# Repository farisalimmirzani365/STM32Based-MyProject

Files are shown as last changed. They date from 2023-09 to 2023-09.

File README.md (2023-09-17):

# STM32Based-MyProject
The Board is based on the STM32 microcontroller, with the Blue Pill STM32F103 serving as the reference material for schematic design. This board is equipped with communication options, either the nRF24L01 or LoRa-02, which can be externally selected according to the user's preference. Additionally, the board features an integrated ADXL345 sensor. It includes a TF-Card for additional data storage. Furthermore, the board can be augmented with an external TFT LCD, which users can purchase separately.

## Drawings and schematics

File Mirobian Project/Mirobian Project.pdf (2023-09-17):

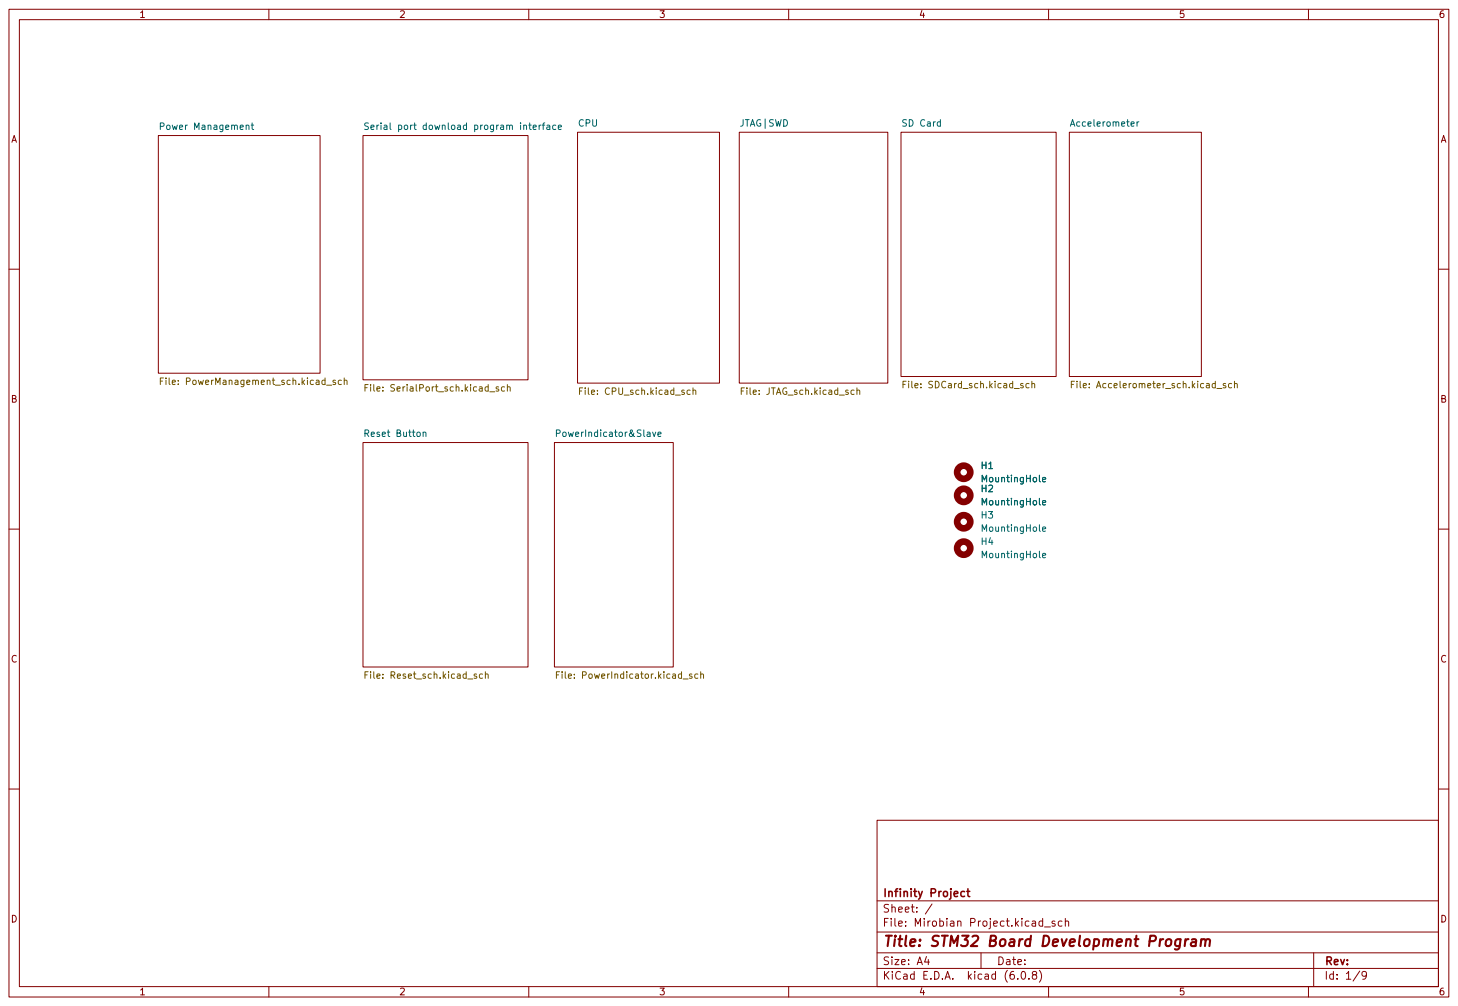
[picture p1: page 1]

Serial port download program interface File: SerialPort_sch.kicad_sch Reset Button File: Reset_sch.kicad_sch

PowerIndicator&Slave File: PowerIndicator.kicad_sch

Infinity Project
File: Mirobian Project.kicad_sch Sheet: /
Id: 1/9 Title: STM32 Board Development Program

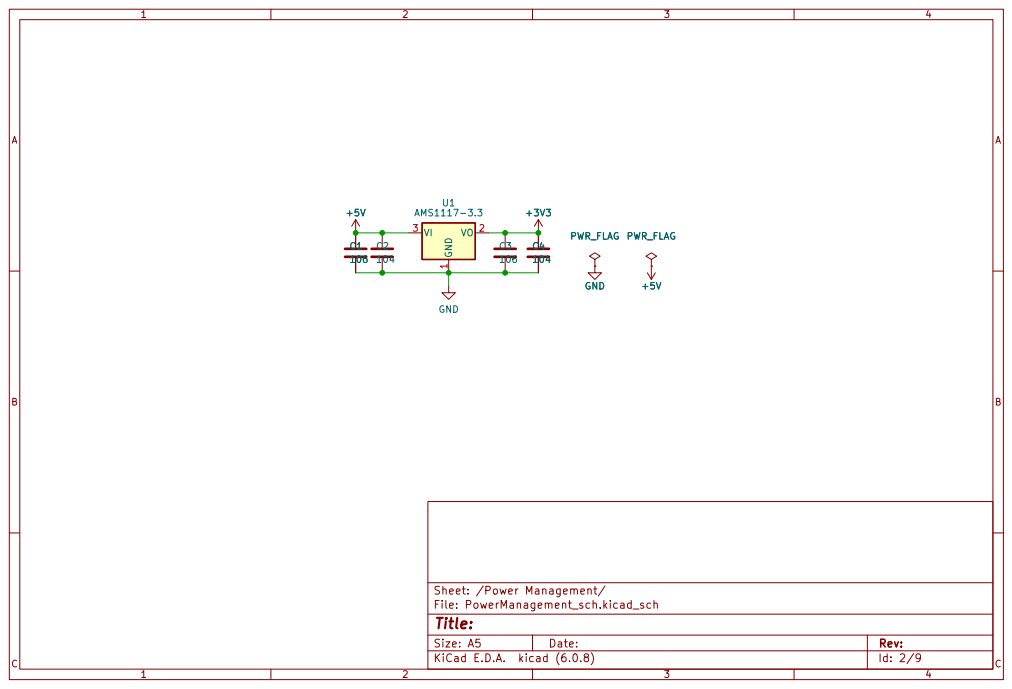
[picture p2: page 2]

Sheet: /Power Management/ GND

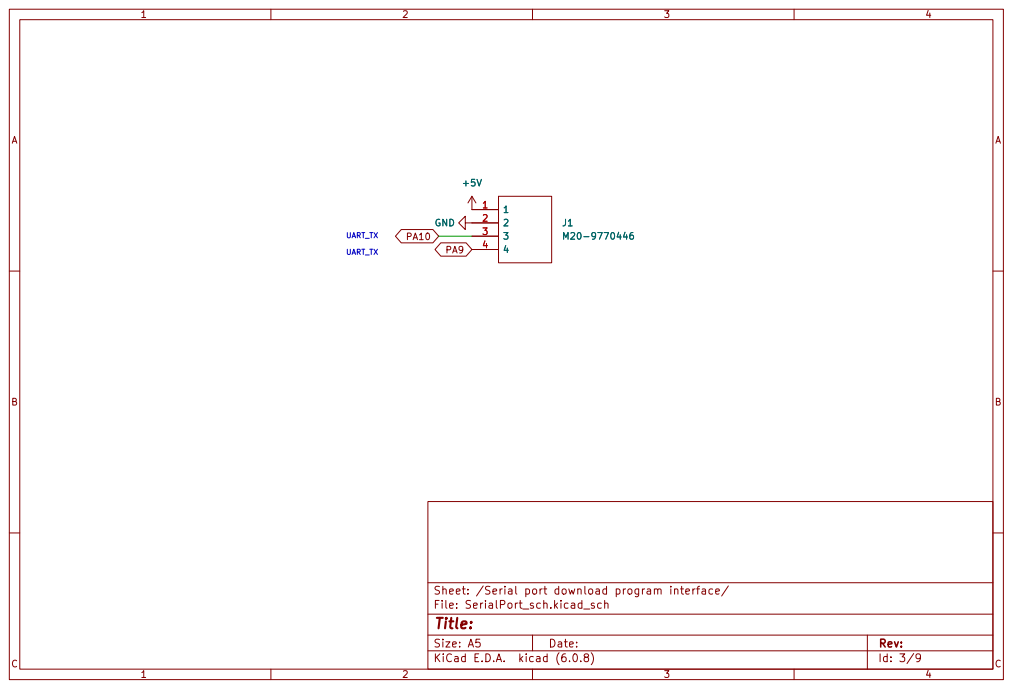
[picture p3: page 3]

Sheet: /Serial port download program interface/ GND

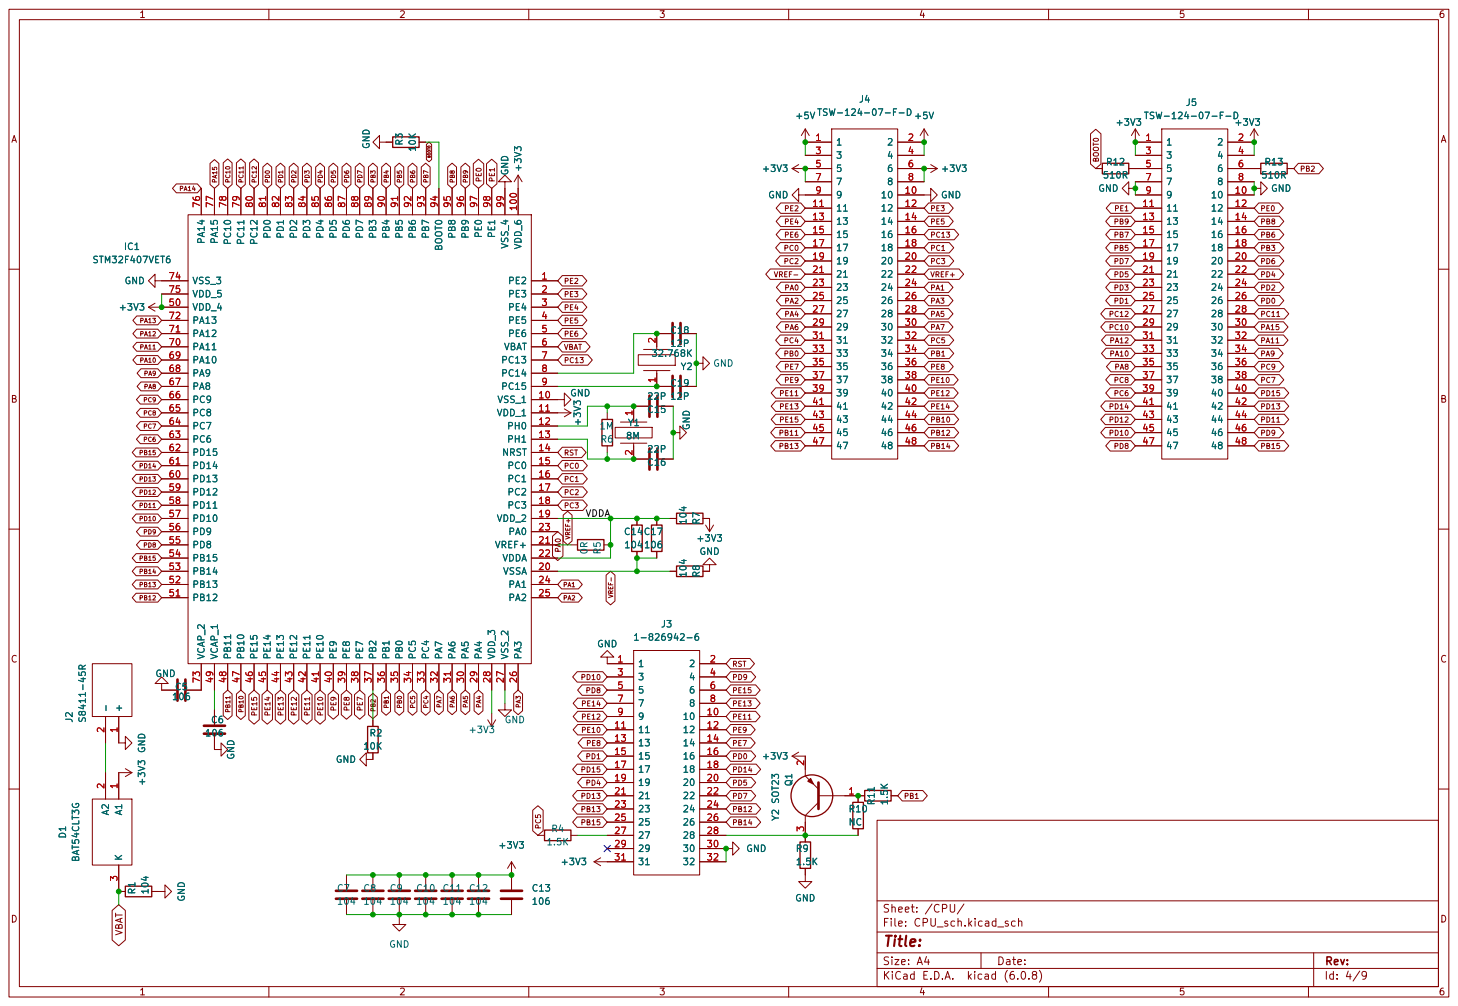
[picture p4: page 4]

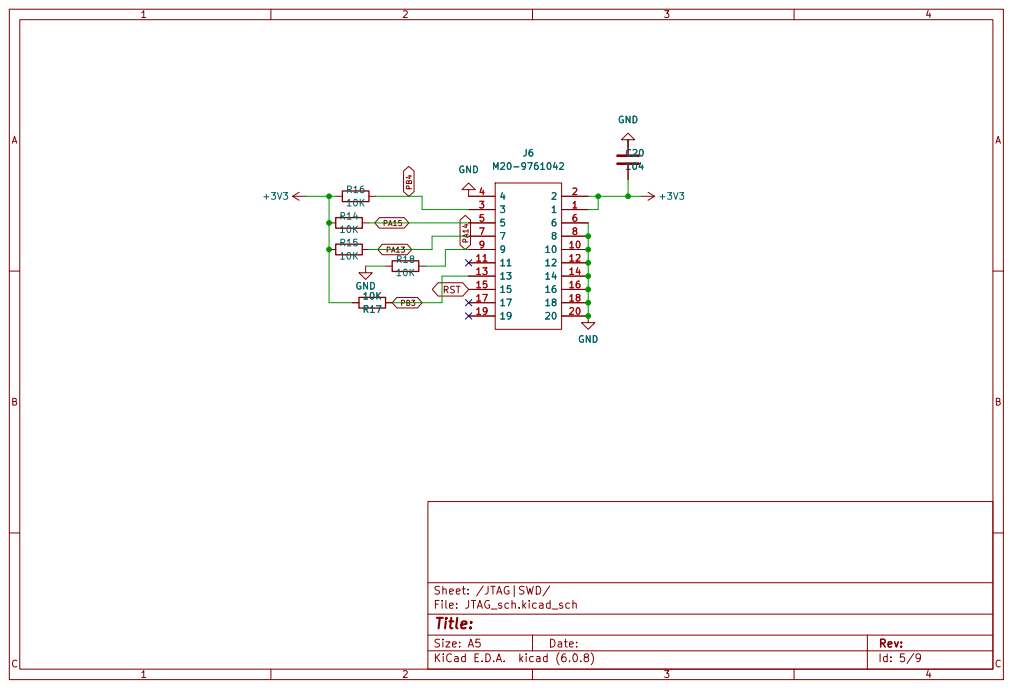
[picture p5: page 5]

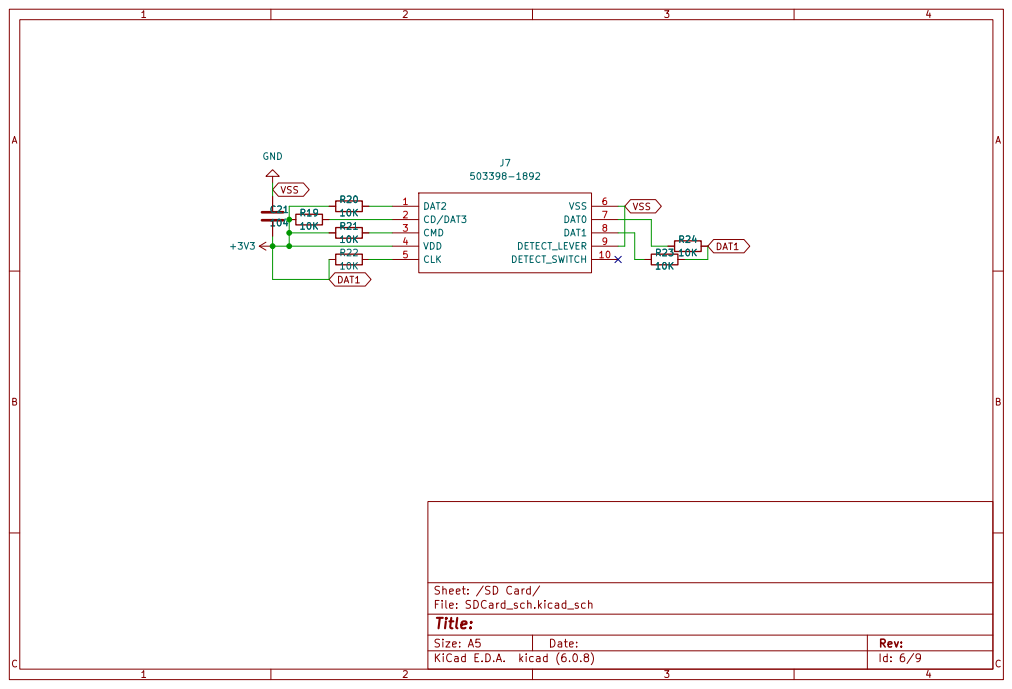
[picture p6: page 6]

File: SDCard_sch.kicad_sch Sheet: /SD Card/ R19

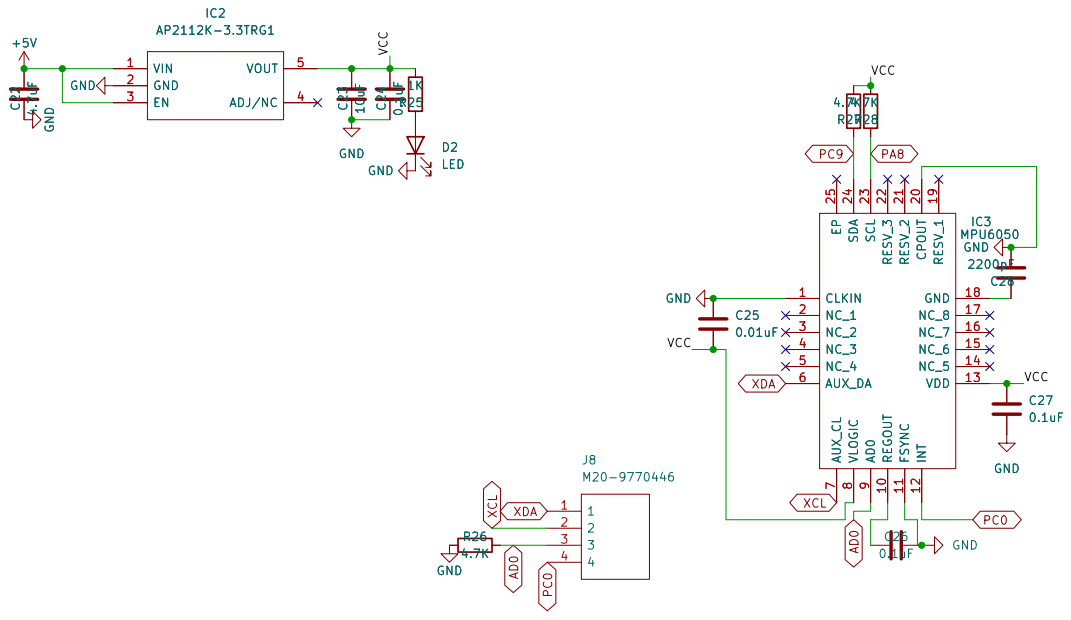
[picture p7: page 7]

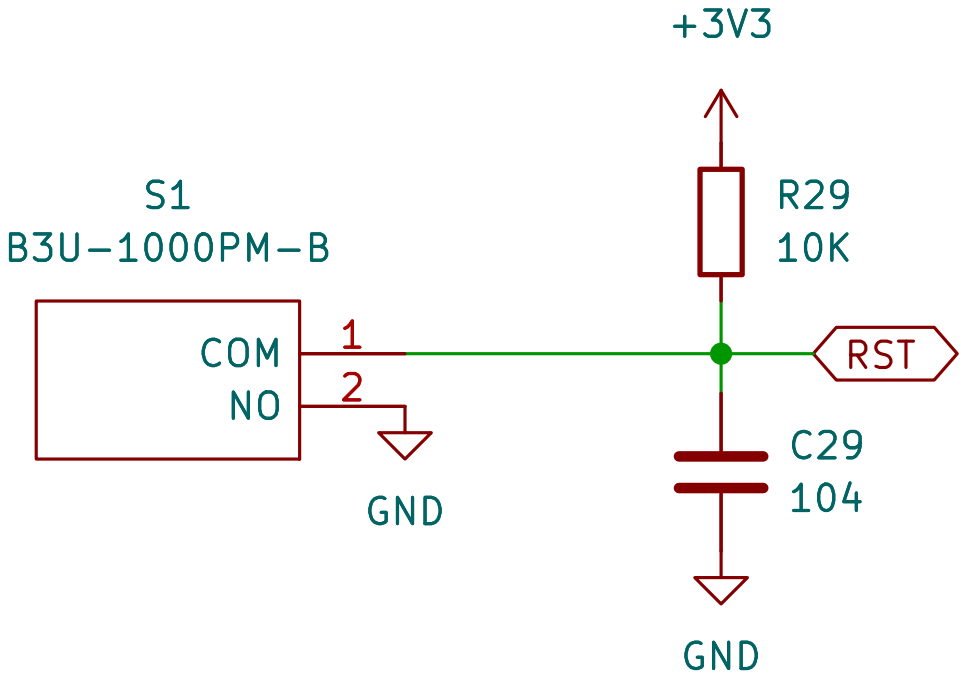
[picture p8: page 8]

File: Reset_sch.kicad_sch Sheet: /Reset Button/
Id: 8/9 Title:

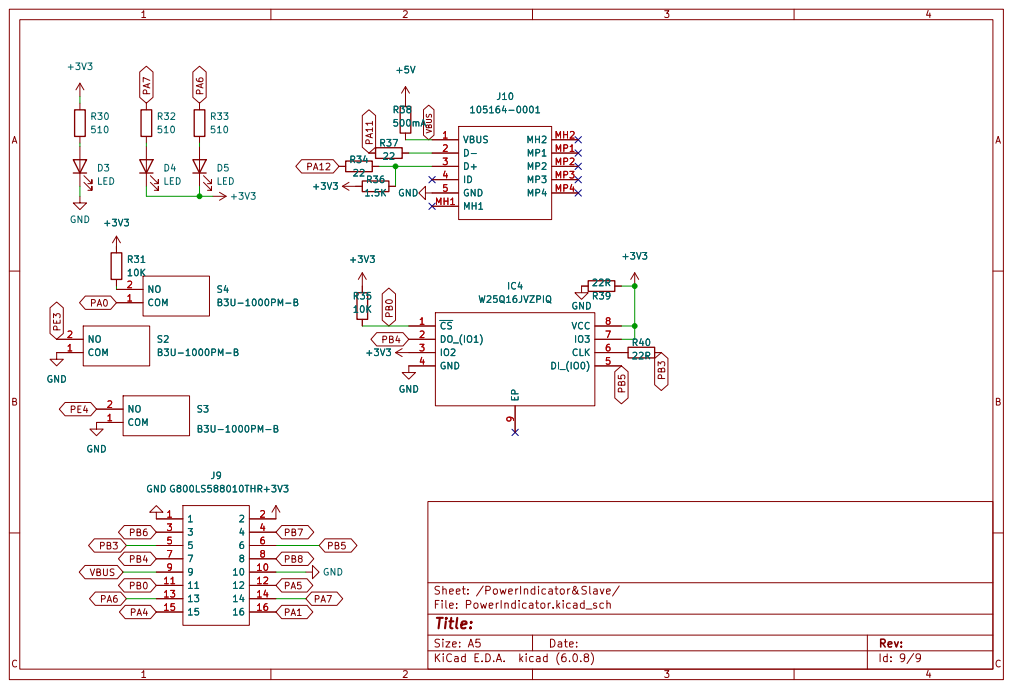
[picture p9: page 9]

File: PowerIndicator.kicad_sch Sheet: /PowerIndicator&Slave/

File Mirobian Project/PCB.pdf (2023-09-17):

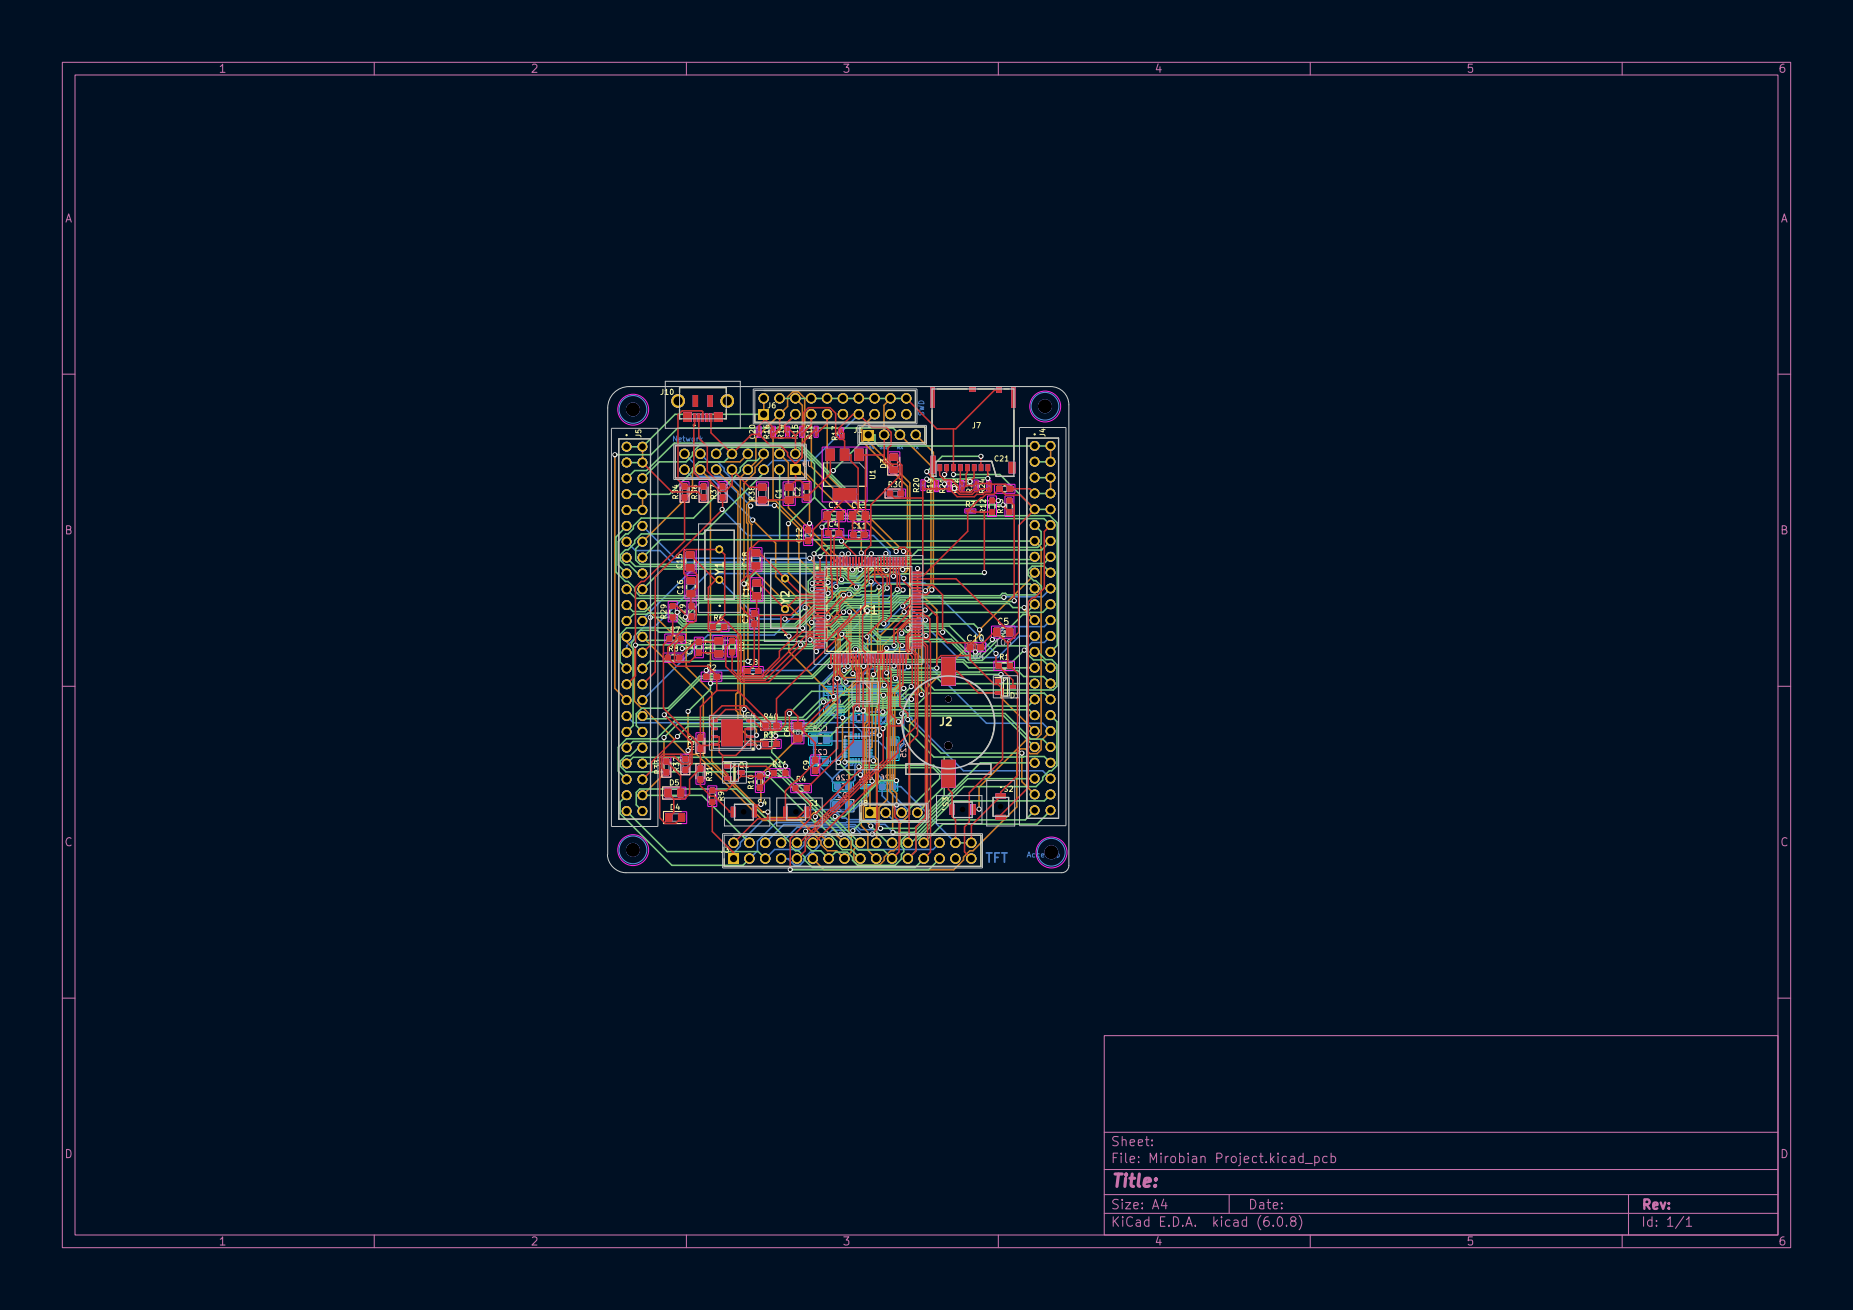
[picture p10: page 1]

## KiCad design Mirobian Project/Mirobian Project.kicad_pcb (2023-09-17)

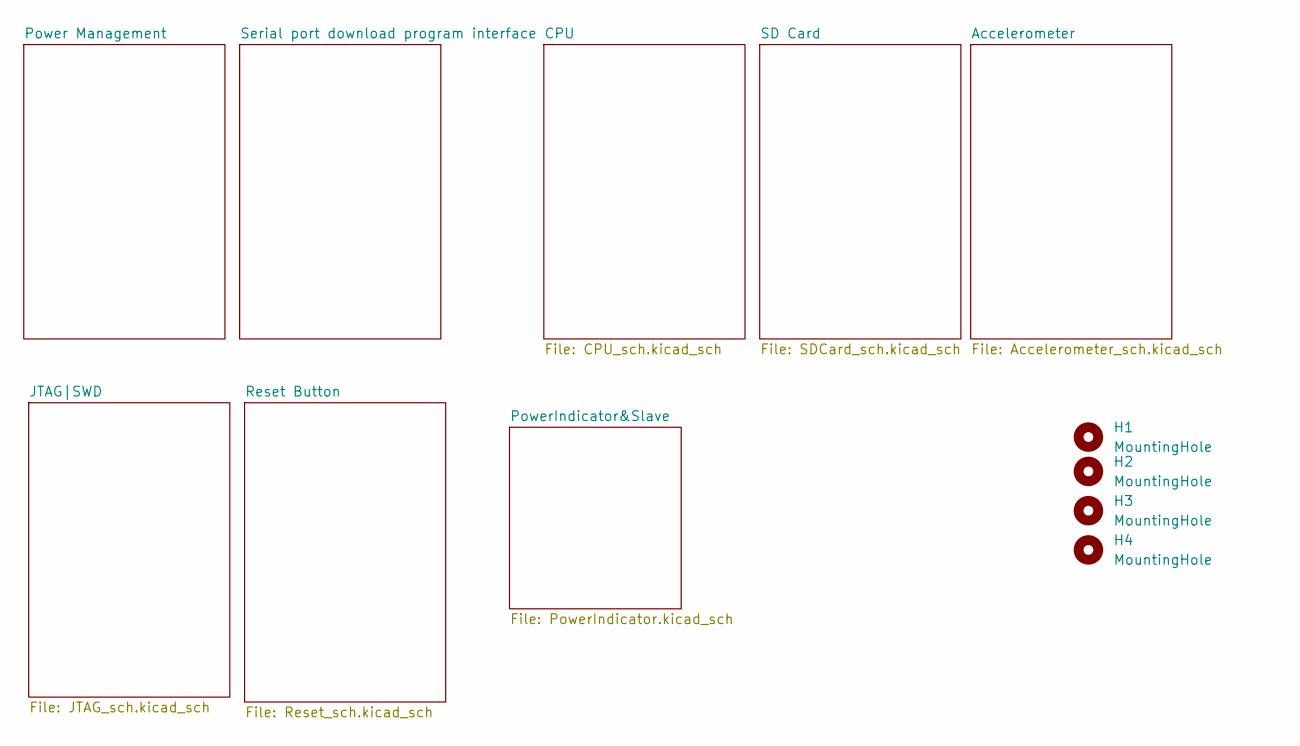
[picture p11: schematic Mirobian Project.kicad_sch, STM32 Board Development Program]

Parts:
H1, H2, H3, H4: MountingHole; MountingHole_2.2mm_M2

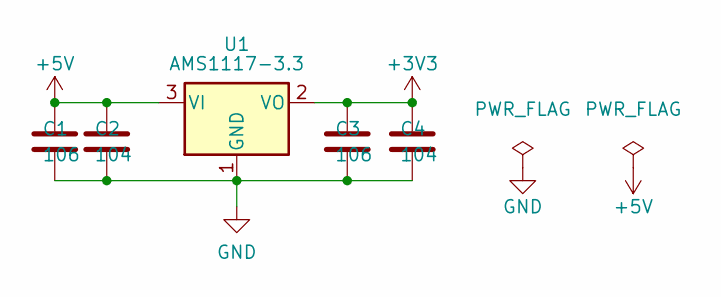
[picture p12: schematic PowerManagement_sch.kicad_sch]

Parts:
C1, C3: 106; C_0805_2012Metric_Pad1.18x1.45mm_HandSolder
C2, C4: 104; C_0603_1608Metric_Pad1.08x0.95mm_HandSolder
U1: AMS1117-3.3; SOT-223-3_TabPin2

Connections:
+5V: C1.1, C2.1, U1.3 (VI); also elsewhere on the board
DAT1: C3.1, C4.1, U1.2 (VO); also elsewhere on the board
VSS: C1.2, C2.2, C3.2, C4.2, U1.1 (GND); also elsewhere on the board

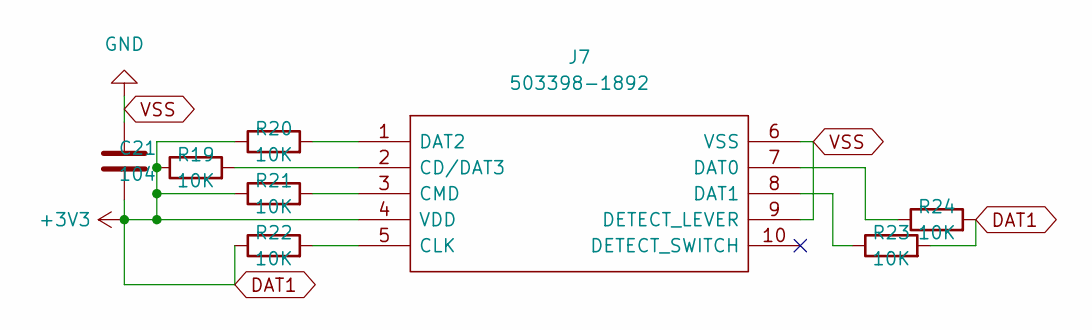
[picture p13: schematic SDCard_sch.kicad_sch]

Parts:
C21: 104; C_0603_1608Metric_Pad1.08x0.95mm_HandSolder
J7: 503398-1892; Manufacturer_Part_Number 503398-1892; Mouser Part Number 538-503398-1892
R19, R20, R21, R22, R23, R24: 10K; R_0201_0603Metric_Pad0.64x0.40mm_HandSolder

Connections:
DAT1: C21.2, J7.4 (VDD), R19.1, R20.1, R21.1, R22.1, R23.2, R24.2; also elsewhere on the board
unnamed: J7.1 (DAT2), R20.2
unnamed: J7.2 (CD/DAT3), R19.2
unnamed: J7.3 (CMD), R21.2
unnamed: J7.5 (CLK), R22.2
unnamed: J7.7 (DAT0), R24.1
unnamed: J7.8 (DAT1), R23.1
VSS: C21.1, J7.6 (VSS), J7.9 (DETECT_LEVER); also elsewhere on the board

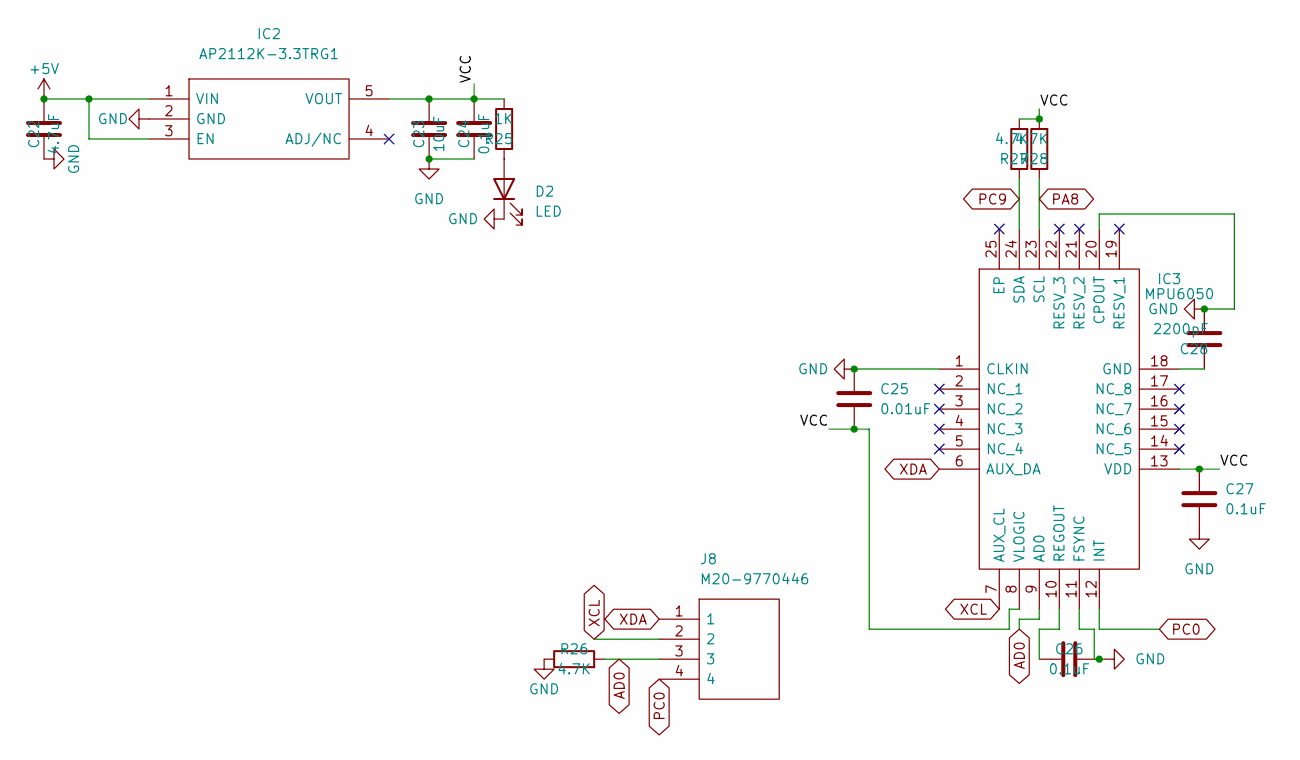
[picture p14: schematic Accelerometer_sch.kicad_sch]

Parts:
C22: 4.7uF; C_0603_1608Metric_Pad1.08x0.95mm_HandSolder
C23: 10uF; C_0603_1608Metric_Pad1.08x0.95mm_HandSolder
C24, C26, C27: 0.1uF; C_0603_1608Metric_Pad1.08x0.95mm_HandSolder
C25: 0.01uF; C_0805_2012Metric_Pad1.18x1.45mm_HandSolder
C28: 2200pF; C_0805_2012Metric_Pad1.18x1.45mm_HandSolder
D2: LED; LED_0805_2012Metric_Pad1.15x1.40mm_HandSolder
IC2: AP2112K-3.3TRG1; SOT95P282X130-5N; Manufacturer_Part_Number AP2112K-3.3TRG1; Mouser Part Number 621-AP2112K-3.3TRG1
IC3: MPU6050; Manufacturer_Part_Number MPU6050
J8: M20-9770446; HDRV4W64P0X254_1X4_1016X254X834P; Manufacturer_Part_Number M20-9770446; Mouser Part Number 855-M20-9770446
R25: 1K; R_0201_0603Metric_Pad0.64x0.40mm_HandSolder
R26, R27, R28: 4.7K; C_0603_1608Metric_Pad1.08x0.95mm_HandSolder

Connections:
+5V: C22.2, IC2.1 (VIN), IC2.3 (EN); also elsewhere on the board
/Accelerometer/VCC: C23.2, C24.2, C25.2, C27.1, IC2.5 (VOUT), IC3.8 (VLOGIC), IC3.13 (VDD), R25.2, R27.2, R28.2
AD0: IC3.9 (AD0), J8.3, R26.2
unnamed: C26.1, IC3.10 (REGOUT)
unnamed: C28.1, IC3.18 (GND)
unnamed: D2.2 (A), R25.1
PA8: IC3.23 (SCL), R28.1; also elsewhere on the board
PC0: IC3.12 (INT), J8.4; also elsewhere on the board
PC9: IC3.24 (SDA), R27.1; also elsewhere on the board
VSS: C22.1, C23.1, C24.1, C25.1, C26.2, C27.2, C28.2, D2.1 (K), IC2.2 (GND), IC3.1 (CLKIN), IC3.11 (FSYNC), IC3.20 (CPOUT), R26.1; also elsewhere on the board
XCL: IC3.7 (AUX_CL), J8.2
XDA: IC3.6 (AUX_DA), J8.1

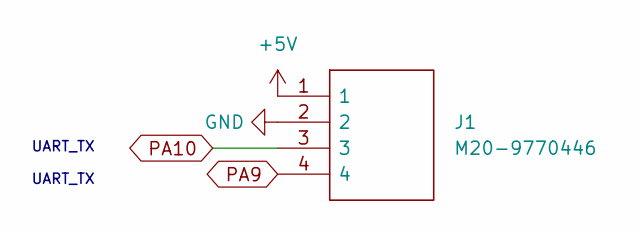
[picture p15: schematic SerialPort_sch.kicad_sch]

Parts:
J1: M20-9770446; HDRV4W64P0X254_1X4_1016X254X834P; Manufacturer_Part_Number M20-9770446; Mouser Part Number 855-M20-9770446

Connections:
+5V: J1.1; also elsewhere on the board
PA9: J1.4; also elsewhere on the board
PA10: J1.3; also elsewhere on the board
VSS: J1.2; also elsewhere on the board

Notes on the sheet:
UART_TX

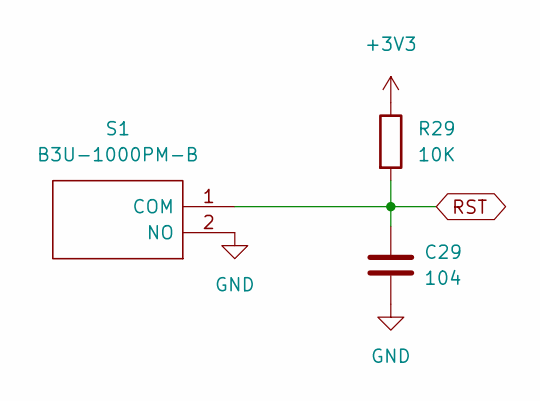
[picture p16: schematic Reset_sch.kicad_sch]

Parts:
C29: 104; C_0603_1608Metric_Pad1.08x0.95mm_HandSolder
R29: 10K; R_0603_1608Metric_Pad0.98x0.95mm_HandSolder
S1: B3U-1000PM-B; B3U1000PMB; Manufacturer_Part_Number B3U-1000PM-B; Mouser Part Number 653-B3U-1000PM-B

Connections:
DAT1: R29.1; also elsewhere on the board
RST: C29.1, R29.2, S1.1 (COM); also elsewhere on the board
VSS: C29.2, S1.2 (NO); also elsewhere on the board

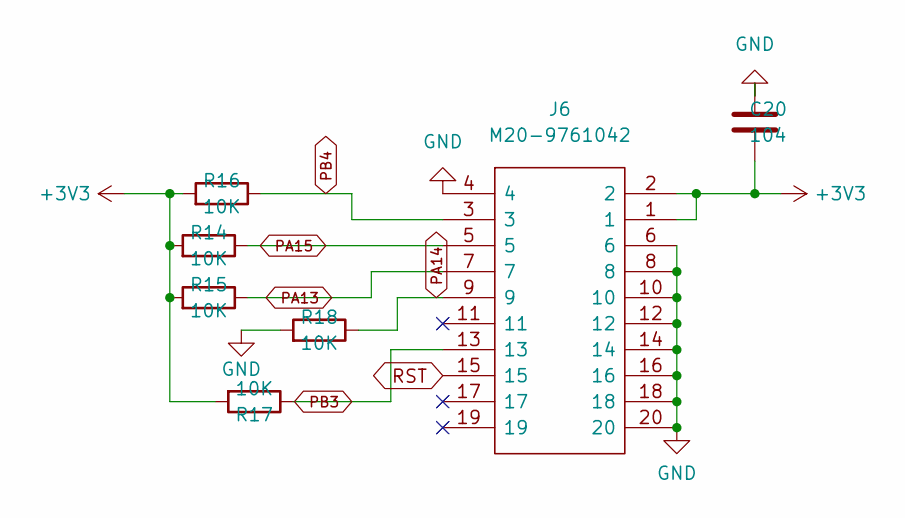
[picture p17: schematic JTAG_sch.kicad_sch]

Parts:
C20: 104; C_0201_0603Metric_Pad0.64x0.40mm_HandSolder
J6: M20-9761042; HDRV20W64P254_2X10_2540X508X838P; Manufacturer_Part_Number M20-9761042; Mouser Part Number 855-M20-9761042
R14, R15, R16, R17, R18: 10K; R_0201_0603Metric_Pad0.64x0.40mm_HandSolder

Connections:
DAT1: C20.2, J6.1, J6.2, R14.2, R15.2, R16.2, R17.2; also elsewhere on the board
PA13: J6.7, R15.1; also elsewhere on the board
PA14: J6.9, R18.1; also elsewhere on the board
PA15: J6.5, R14.1; also elsewhere on the board
PB3: J6.13, R17.1; also elsewhere on the board
PB4: J6.3, R16.1; also elsewhere on the board
RST: J6.15; also elsewhere on the board
VSS: C20.1, J6.4, J6.6, J6.8, J6.10, J6.12, J6.14, J6.16, J6.18, J6.20, R18.2; also elsewhere on the board

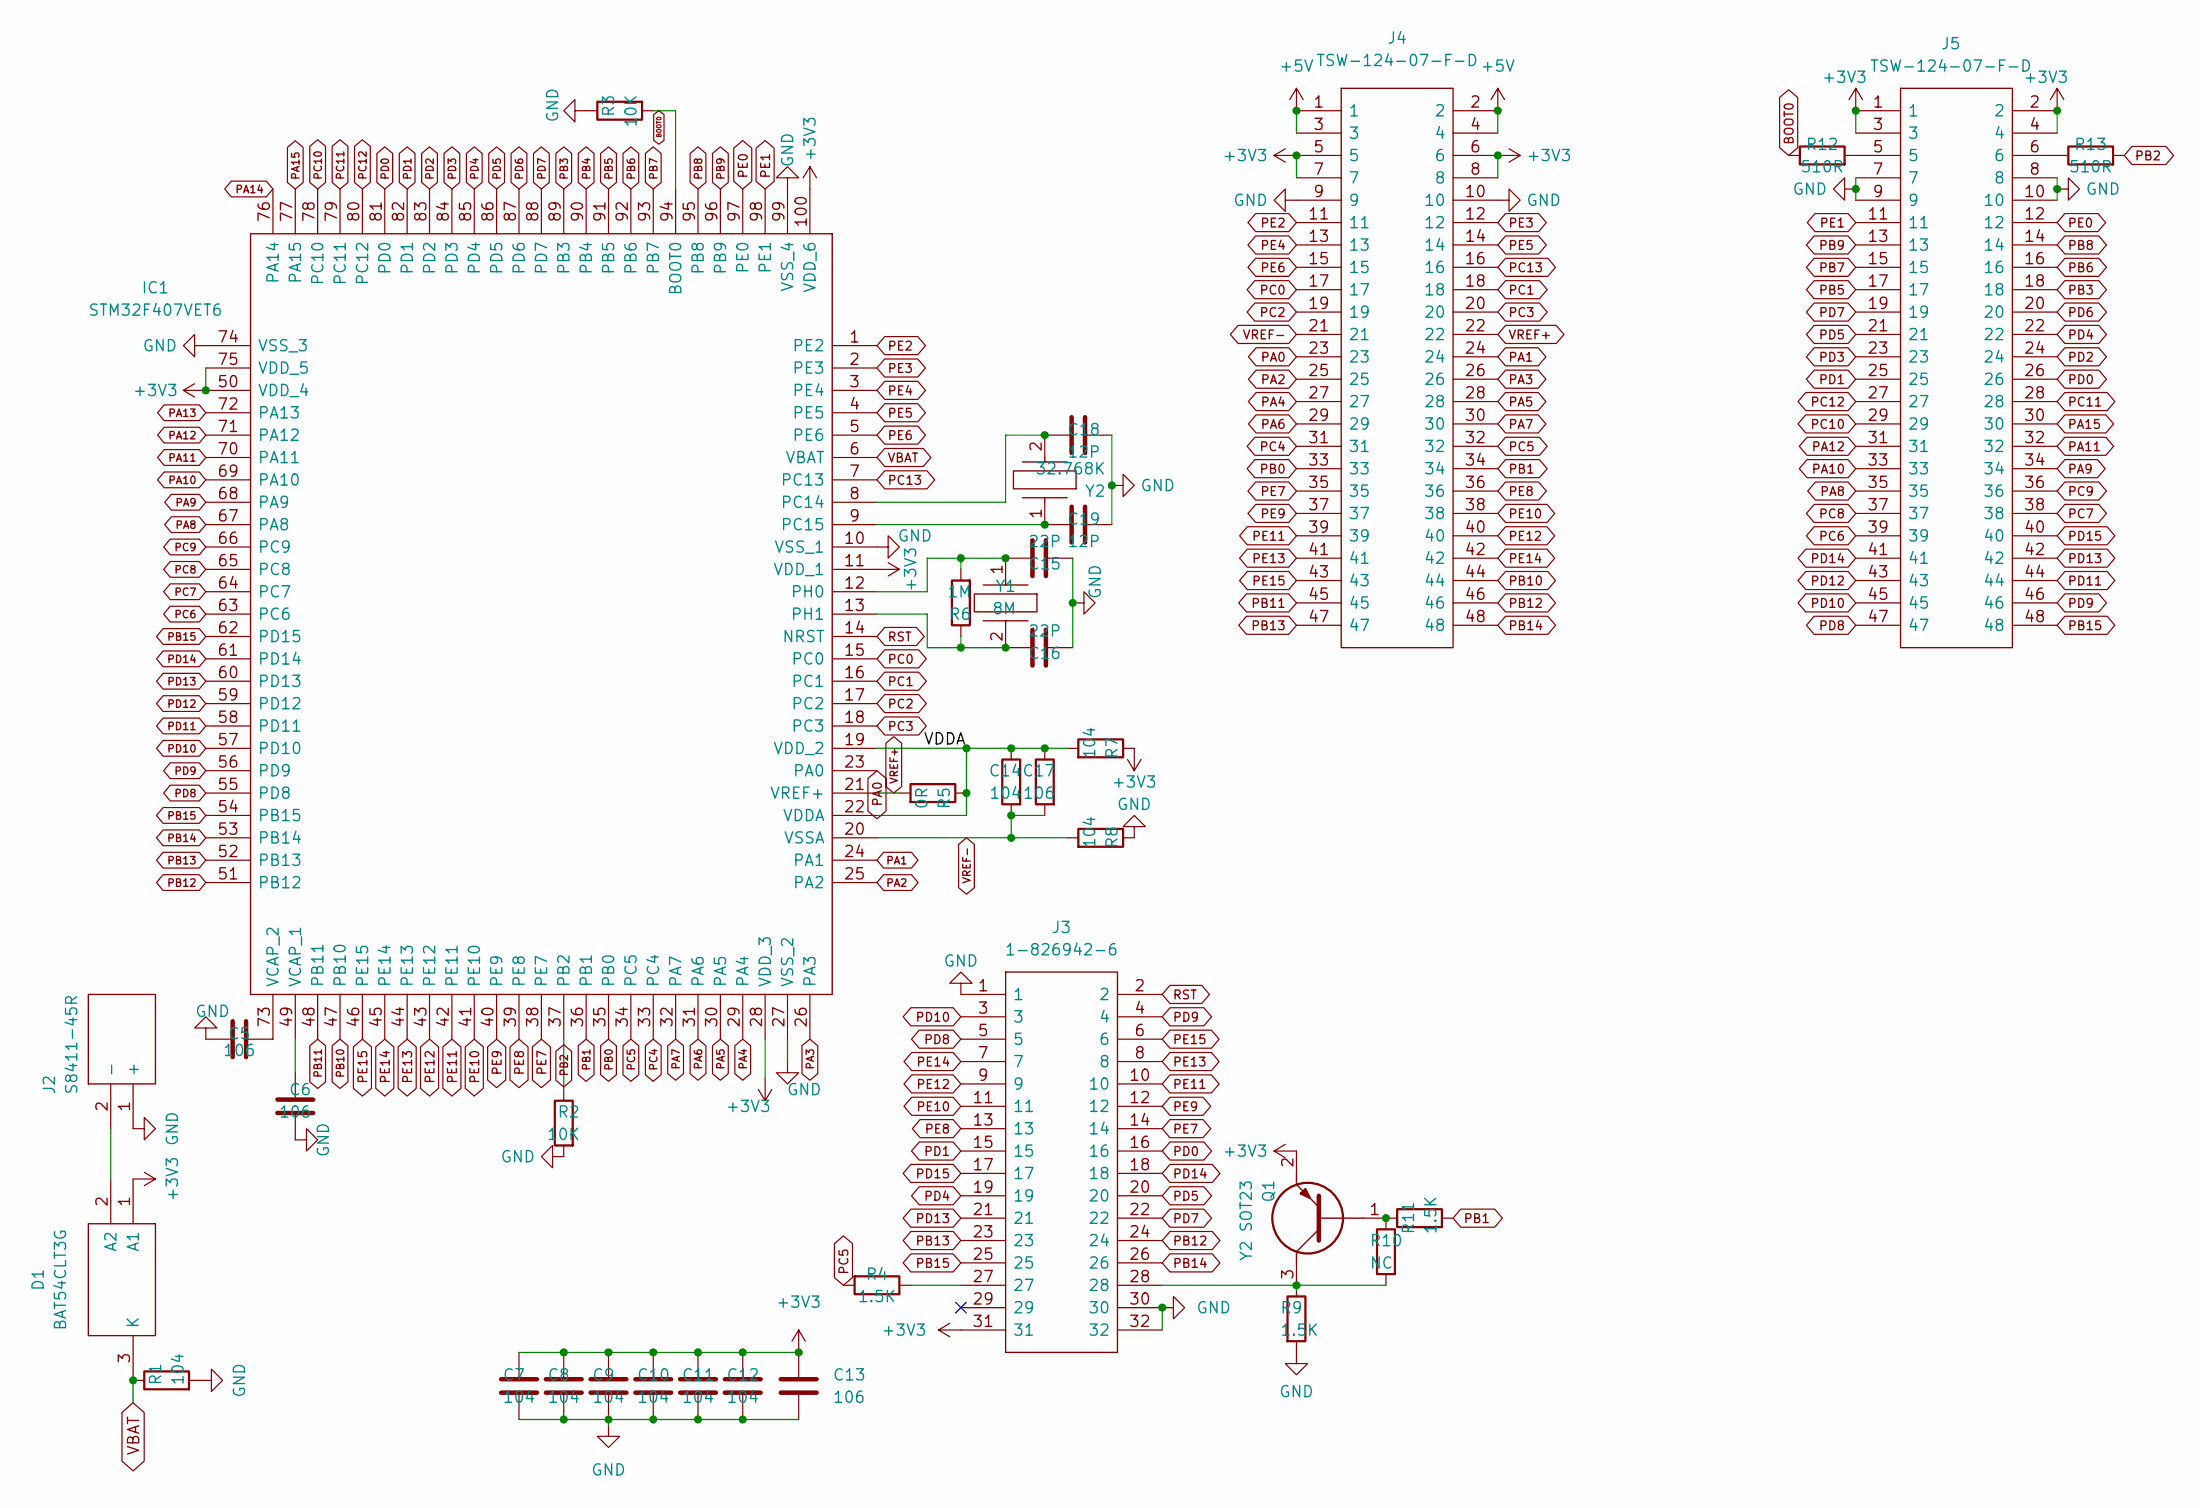
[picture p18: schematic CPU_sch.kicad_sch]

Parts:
C5, C6, C13, C17: 106; C_0805_2012Metric_Pad1.18x1.45mm_HandSolder
C7, C8, C9, C10, C11, C12, C14: 104; C_0603_1608Metric_Pad1.08x0.95mm_HandSolder
C15, C16: 22P; C_0805_2012Metric_Pad1.18x1.45mm_HandSolder
C18, C19: 12P; C_0805_2012Metric_Pad1.18x1.45mm_HandSolder
D1: BAT54CLT3G; SOT96P237X111-3N; Manufacturer_Part_Number BAT54CLT3G; Mouser Part Number 863-BAT54CLT3G
IC1: STM32F407VET6; QFP50P1600X1600X160-100N; Manufacturer_Part_Number STM32F407VET6; Mouser Part Number 511-STM32F407VET6
J2: S8411-45R; S8411-45R_1; Manufacturer_Part_Number S8411-45R; Mouser Part Number 855-S8411-45R
J3: 1-826942-6; HDRV32W63P254_2X16_4114X500X860P; Manufacturer_Part_Number 1-826942-6; Mouser Part Number 571-1-826942-6
J4, J5: TSW-124-07-F-D; TSW-124-XX-YY-D; Manufacturer_Part_Number TSW-124-07-F-D; Mouser Part Number 200-TSW12407FD
Q1: Y2 SOT23; SOT96P240X110-3N; Manufacturer_Part_Number MMBT3906-7-F; Mouser Part Number 621-MMBT3906-F
R1, R7, R8: 104; R_0603_1608Metric_Pad0.98x0.95mm_HandSolder
R2: 10K; C_0603_1608Metric_Pad1.08x0.95mm_HandSolder
R3: 10K; R_0201_0603Metric_Pad0.64x0.40mm_HandSolder
R4, R9, R11: 1.5K; R_0603_1608Metric_Pad0.98x0.95mm_HandSolder
R5: 0R; R_0603_1608Metric_Pad0.98x0.95mm_HandSolder
R6: 1M; R_0603_1608Metric_Pad0.98x0.95mm_HandSolder
R10: NC; R_0603_1608Metric_Pad0.98x0.95mm_HandSolder
R12, R13: 510R; R_0603_1608Metric_Pad0.98x0.95mm_HandSolder
Y1: 8M; LFXTAL057135Bulk; Manufacturer_Part_Number LFXTAL057135Bulk; Mouser Part Number 449-LFXTAL057135BULK
Y2: 32.768K; LFXTAL057135Bulk; Manufacturer_Part_Number LFXTAL057135Bulk; Mouser Part Number 449-LFXTAL057135BULK

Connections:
+5V: J4.1, J4.2, J4.3, J4.4; also elsewhere on the board
/CPU/VDDA: C14.1, C17.1, IC1.19 (VDD_2), IC1.22 (VDDA), R5.1, R7.2
BOOT0: IC1.94 (BOOT0), R3.2, R12.1
DAT1: C7.1, C8.1, C9.1, C10.1, C11.1, C12.1, C13.1, D1.1 (A1), IC1.11 (VDD_1), IC1.28 (VDD_3), IC1.50 (VDD_4), IC1.75 (VDD_5), IC1.100 (VDD_6), J3.31, J4.5, J4.6, J4.7, J4.8, J5.1, J5.2, J5.3, J5.4, Q1.2, R7.1; also elsewhere on the board
unnamed: C5.2, IC1.73 (VCAP_2)
unnamed: C6.1, IC1.49 (VCAP_1)
unnamed: C15.2, IC1.12 (PH0), R6.2, Y1.1
unnamed: C16.2, IC1.13 (PH1), R6.1, Y1.2
unnamed: C18.2, IC1.8 (PC14), Y2.2
unnamed: C19.2, IC1.9 (PC15), Y2.1
unnamed: D1.2 (A2), J2.2 (-)
unnamed: J3.27, R4.1
unnamed: J3.28, Q1.3, R9.1, R10.2
unnamed: J5.5, R12.2
unnamed: J5.6, R13.1
unnamed: Q1.1, R10.1, R11.1
PA0: IC1.23 (PA0), J4.23; also elsewhere on the board
PA1: IC1.24 (PA1), J4.24; also elsewhere on the board
PA2: IC1.25 (PA2), J4.25
PA3: IC1.26 (PA3), J4.26
PA4: IC1.29 (PA4), J4.27; also elsewhere on the board
PA5: IC1.30 (PA5), J4.28; also elsewhere on the board
PA6: IC1.31 (PA6), J4.29; also elsewhere on the board
PA7: IC1.32 (PA7), J4.30; also elsewhere on the board
PA8: IC1.67 (PA8), J5.35; also elsewhere on the board
PA9: IC1.68 (PA9), J5.34; also elsewhere on the board
PA10: IC1.69 (PA10), J5.33; also elsewhere on the board
PA11: IC1.70 (PA11), J5.32; also elsewhere on the board
PA12: IC1.71 (PA12), J5.31; also elsewhere on the board
PA13: IC1.72 (PA13); also elsewhere on the board
PA14: IC1.76 (PA14); also elsewhere on the board
PA15: IC1.77 (PA15), J5.30; also elsewhere on the board
PB0: IC1.35 (PB0), J4.33; also elsewhere on the board
PB1: IC1.36 (PB1), J4.34, R11.2
PB2: IC1.37 (PB2), R2.1, R13.2
PB3: IC1.89 (PB3), J5.18; also elsewhere on the board
PB4: IC1.90 (PB4); also elsewhere on the board
PB5: IC1.91 (PB5), J5.17; also elsewhere on the board
PB6: IC1.92 (PB6), J5.16; also elsewhere on the board
PB7: IC1.93 (PB7), J5.15; also elsewhere on the board
PB8: IC1.95 (PB8), J5.14; also elsewhere on the board
PB9: IC1.96 (PB9), J5.13
PB10: IC1.47 (PB10), J4.44
PB11: IC1.48 (PB11), J4.45
PB12: IC1.51 (PB12), J3.24, J4.46
PB13: IC1.52 (PB13), J3.23, J4.47
PB14: IC1.53 (PB14), J3.26, J4.48
PB15: IC1.54 (PB15), IC1.62 (PD15), J3.25, J5.48
PC0: IC1.15 (PC0), J4.17; also elsewhere on the board
PC1: IC1.16 (PC1), J4.18
PC2: IC1.17 (PC2), J4.19
PC3: IC1.18 (PC3), J4.20
PC4: IC1.33 (PC4), J4.31
PC5: IC1.34 (PC5), J4.32, R4.2
PC6: IC1.63 (PC6), J5.39
PC7: IC1.64 (PC7), J5.38
PC8: IC1.65 (PC8), J5.37
PC9: IC1.66 (PC9), J5.36; also elsewhere on the board
PC10: IC1.78 (PC10), J5.29
PC11: IC1.79 (PC11), J5.28
PC12: IC1.80 (PC12), J5.27
PC13: IC1.7 (PC13), J4.16
PD0: IC1.81 (PD0), J3.16, J5.26
PD1: IC1.82 (PD1), J3.15, J5.25
PD2: IC1.83 (PD2), J5.24
PD3: IC1.84 (PD3), J5.23
PD4: IC1.85 (PD4), J3.19, J5.22
PD5: IC1.86 (PD5), J3.20, J5.21
PD6: IC1.87 (PD6), J5.20
PD7: IC1.88 (PD7), J3.22, J5.19
PD8: IC1.55 (PD8), J3.5, J5.47
PD9: IC1.56 (PD9), J3.4, J5.46
PD10: IC1.57 (PD10), J3.3, J5.45
PD11: IC1.58 (PD11), J5.44
PD12: IC1.59 (PD12), J5.43
PD13: IC1.60 (PD13), J3.21, J5.42
PD14: IC1.61 (PD14), J3.18, J5.41
PD15: J3.17, J5.40
PE0: IC1.97 (PE0), J5.12
PE1: IC1.98 (PE1), J5.11
PE2: IC1.1 (PE2), J4.11
PE3: IC1.2 (PE3), J4.12; also elsewhere on the board
PE4: IC1.3 (PE4), J4.13; also elsewhere on the board
PE5: IC1.4 (PE5), J4.14
PE6: IC1.5 (PE6), J4.15
PE7: IC1.38 (PE7), J3.14, J4.35
PE8: IC1.39 (PE8), J3.13, J4.36
PE9: IC1.40 (PE9), J3.12, J4.37
PE10: IC1.41 (PE10), J3.11, J4.38
PE11: IC1.42 (PE11), J3.10, J4.39
PE12: IC1.43 (PE12), J3.9, J4.40
PE13: IC1.44 (PE13), J3.8, J4.41
PE14: IC1.45 (PE14), J3.7, J4.42
PE15: IC1.46 (PE15), J3.6, J4.43
RST: IC1.14 (NRST), J3.2; also elsewhere on the board
VBAT: D1.3 (K), IC1.6 (VBAT), R1.1
VREF+: IC1.21 (VREF+), J4.22, R5.2
VREF-: C14.2, C17.2, IC1.20 (VSSA), J4.21, R8.2
VSS: C5.1, C6.2, C7.2, C8.2, C9.2, C10.2, C11.2, C12.2, C13.2, C15.1, C16.1, C18.1, C19.1, IC1.10 (VSS_1), IC1.27 (VSS_2), IC1.74 (VSS_3), IC1.99 (VSS_4), J2.1 (+), J3.1, J3.30, J3.32, J4.9, J4.10, J5.7, J5.8, J5.9, J5.10, R1.2, R2.2, R3.1, R8.1, R9.2; also elsewhere on the board

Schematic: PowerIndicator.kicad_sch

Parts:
D3, D4, D5: LED; LED_0805_2012Metric_Pad1.15x1.40mm_HandSolder
IC4: W25Q16JVZPIQ; SON127P600X500X80-9N-D; Manufacturer_Part_Number W25Q16JVZPIQ; Mouser Part Number 454-W25Q16JVZPIQ
J9: G800LS588010THR; HDRV16W64P254_2X8_2032X500X885P; Manufacturer_Part_Number G800LS588010THR; Mouser Part Number 523-G800LS588010THR
J10: 105164-0001; 1051640001; Manufacturer_Part_Number 105164-0001; Mouser Part Number 538-105164-0001
R30, R32, R33: 510; LED_0603_1608Metric_Pad1.05x0.95mm_HandSolder
R31, R35: 10K; LED_0603_1608Metric_Pad1.05x0.95mm_HandSolder
R34, R37: 22; LED_0603_1608Metric_Pad1.05x0.95mm_HandSolder
R36: 1.5K; LED_0603_1608Metric_Pad1.05x0.95mm_HandSolder
R38: 500mA; LED_0805_2012Metric_Pad1.15x1.40mm_HandSolder
R39, R40: 22R; LED_0603_1608Metric_Pad1.05x0.95mm_HandSolder
S2, S3, S4: B3U-1000PM-B; B3U1000PMB; Manufacturer_Part_Number B3U-1000PM-B; Mouser Part Number 653-B3U-1000PM-B

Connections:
+5V: R38.1; also elsewhere on the board
DAT1: D4.1 (K), D5.1 (K), IC4.3 (IO2), IC4.7 (IO3), IC4.8 (VCC), J9.2, R30.1, R31.1, R35.1, R36.1, R39.1; also elsewhere on the board
unnamed: D3.2 (A), R30.2
unnamed: D4.2 (A), R32.2
unnamed: D5.2 (A), R33.2
unnamed: IC4.6 (CLK), R40.1
unnamed: J10.2 (D-), R37.2
unnamed: J10.3 (D+), R34.2, R36.2
unnamed: R31.2, S4.2 (NO)
PA0: S4.1 (COM); also elsewhere on the board
PA1: J9.16; also elsewhere on the board
PA4: J9.15; also elsewhere on the board
PA5: J9.12; also elsewhere on the board
PA6: J9.13, R33.1; also elsewhere on the board
PA7: J9.14, R32.1; also elsewhere on the board
PA11: R37.1; also elsewhere on the board
PA12: R34.1; also elsewhere on the board
PB0: IC4.1 (~CS), J9.11, R35.2; also elsewhere on the board
PB3: J9.5, R40.2; also elsewhere on the board
PB4: IC4.2 (DO_(IO1)), J9.7; also elsewhere on the board
PB5: IC4.5 (DI_(IO0)), J9.6; also elsewhere on the board
PB6: J9.3; also elsewhere on the board
PB7: J9.4; also elsewhere on the board
PB8: J9.8; also elsewhere on the board
PE3: S2.2 (NO); also elsewhere on the board
PE4: S3.2 (NO); also elsewhere on the board
VBUS: J9.9, J10.1 (VBUS), R38.2
VSS: D3.1 (K), IC4.4 (GND), J9.1, J9.10, J10.5 (GND), R39.2, S2.1 (COM), S3.1 (COM); also elsewhere on the board

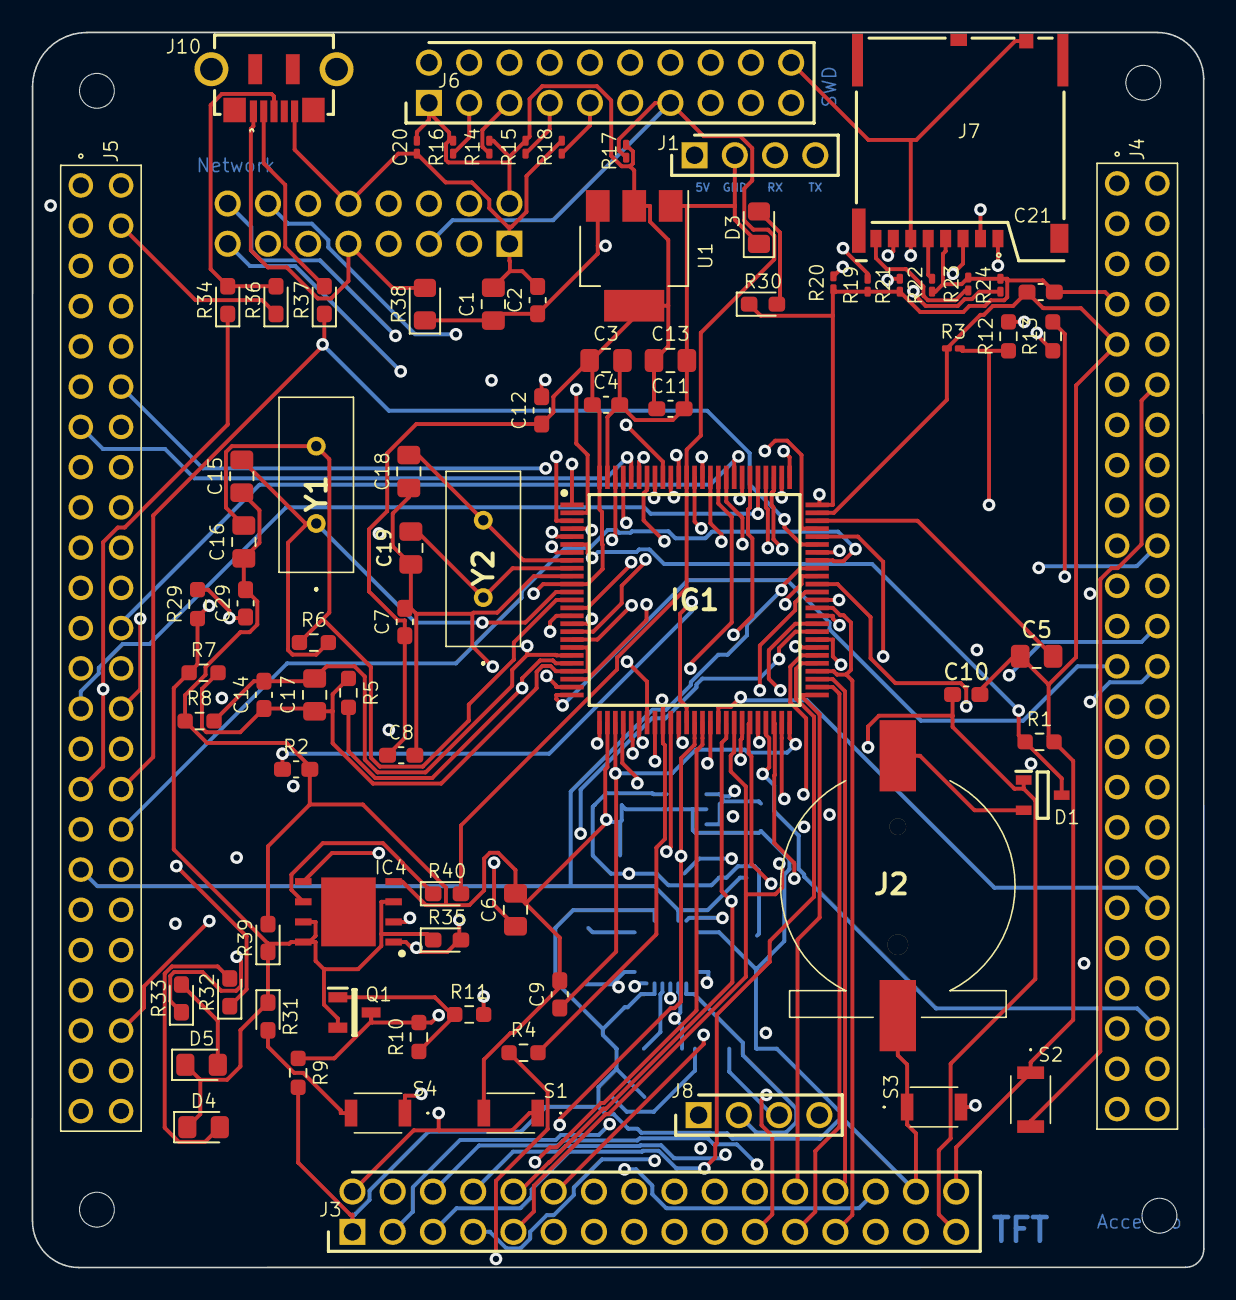
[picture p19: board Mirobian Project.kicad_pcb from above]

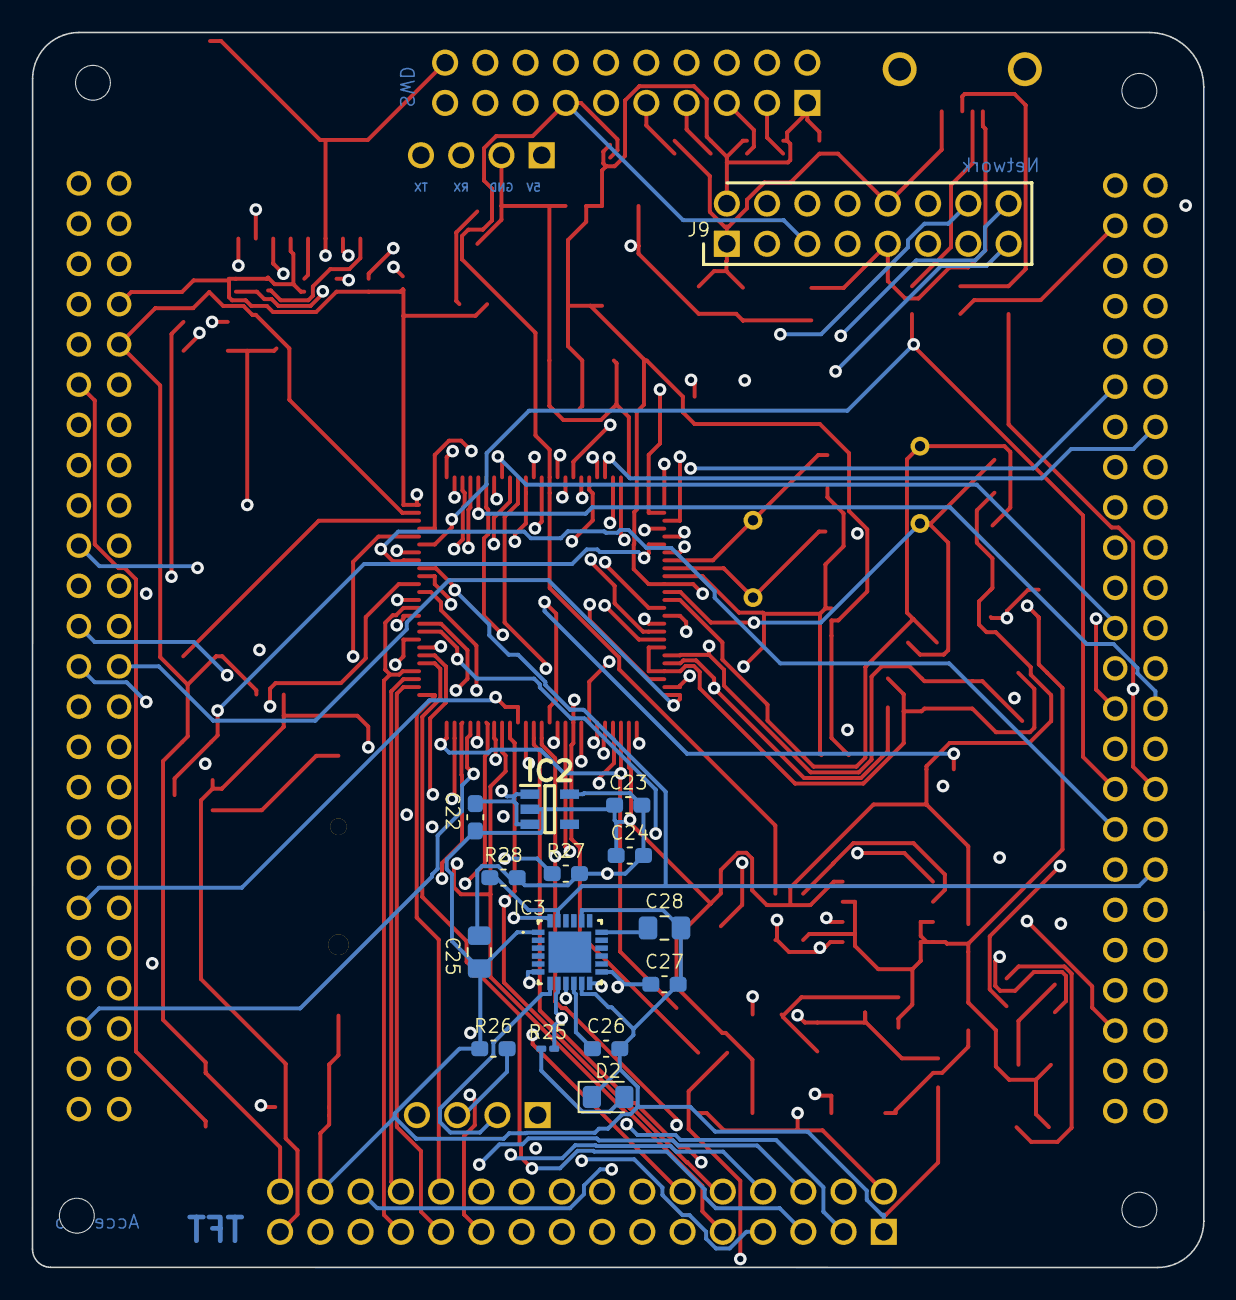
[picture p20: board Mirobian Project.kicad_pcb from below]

Board: 4 copper layers, 73.9 x 77.9 mm, 100 parts (15 on the bottom side), 120 nets.
